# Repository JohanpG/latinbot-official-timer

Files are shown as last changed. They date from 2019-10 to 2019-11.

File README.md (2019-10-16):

# latinbot-official-timer
Project on processing and arduino for the official timer used in the international robotics tournament LATINBOT https://twitter.com/torneolatinbot?lang=en

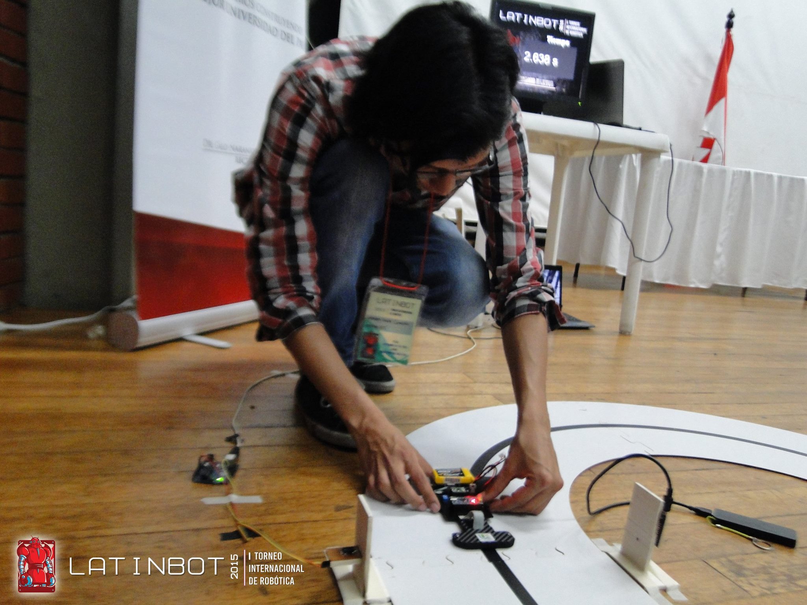
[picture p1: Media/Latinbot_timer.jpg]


# The Sensor

The sensor used was based on a IR Sender and receiver. The PWM on the sender was controller by an Arduino Micro and the Receiver used an Arduino Uno with was conecter via serial to the PC where the processing Application was being executed. Both schematics for the sender and receiver are provided in this repository.

## Sender

[Schematics Here](https://github.com/JohanpG/latinbot-official-timer/blob/master/Schematics/sender.pdf)

## Receiver

[Schematics Here](https://github.com/JohanpG/latinbot-official-timer/blob/master/Schematics/receiver.pdf)
  
# Video

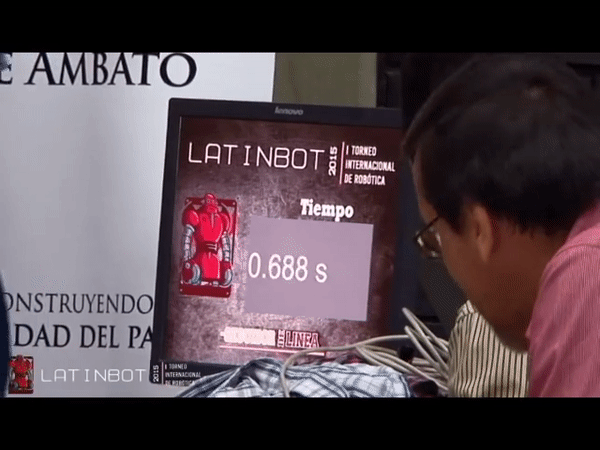
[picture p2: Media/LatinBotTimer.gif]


https://www.youtube.com/watch?v=m9lWtLH9l_A&t=2m27s

# Author

**By: Johan Porras (JohanpG)**

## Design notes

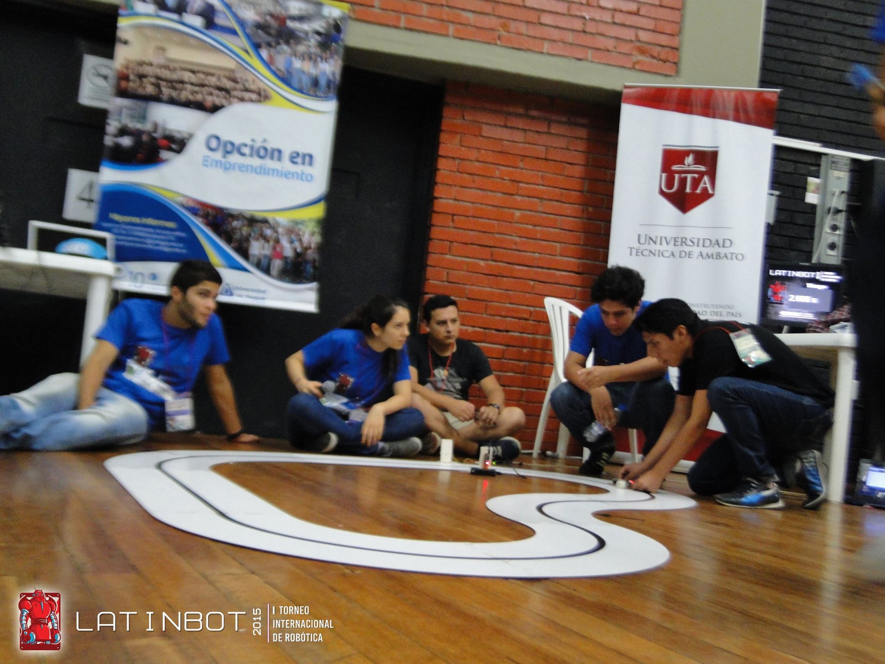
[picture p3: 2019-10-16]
Media/Latinbot_timer2.jpg

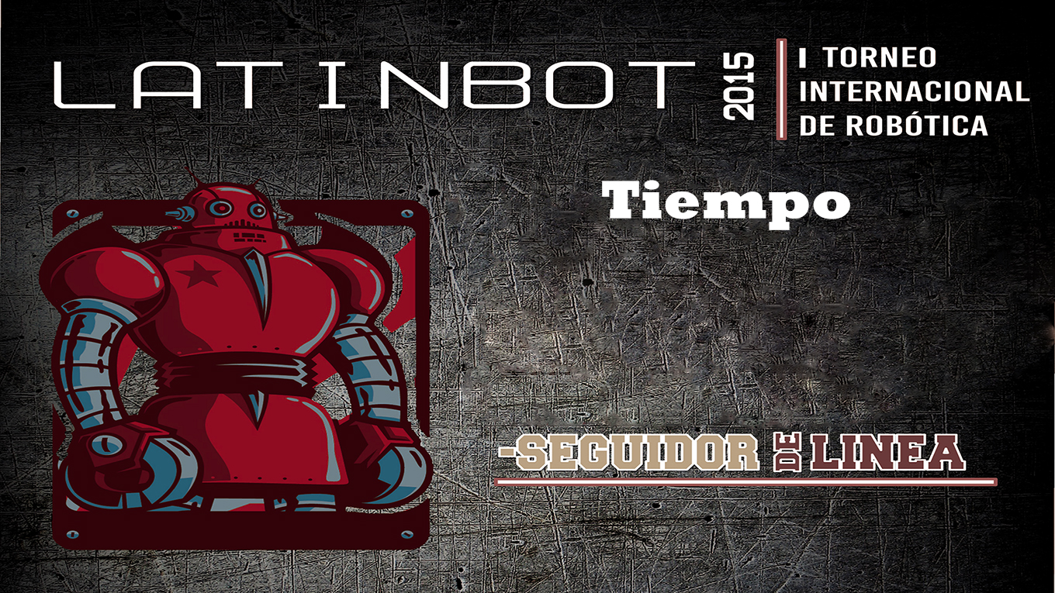
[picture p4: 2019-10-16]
Timer_LatinBot_noArd/images/TimerLatinbot1.jpg

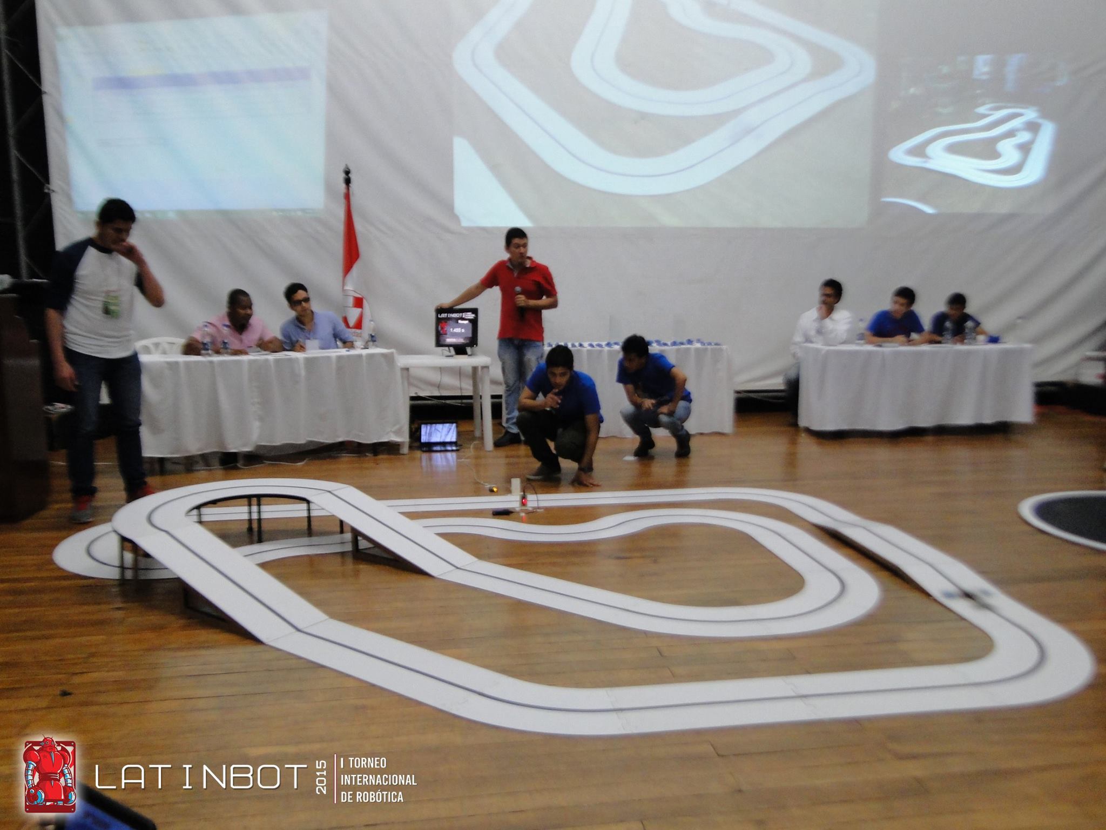
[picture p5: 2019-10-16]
Media/Latinbot_timer3.jpg

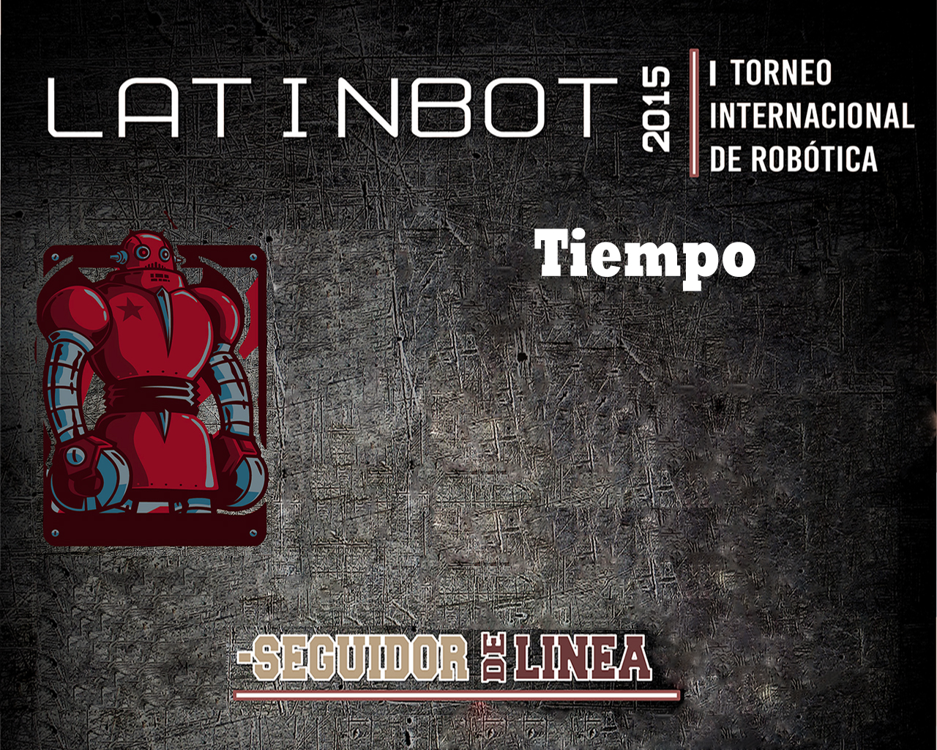
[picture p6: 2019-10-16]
Timer_LatinBot_Live_Sensor/images/TimerLatinbot2.jpg

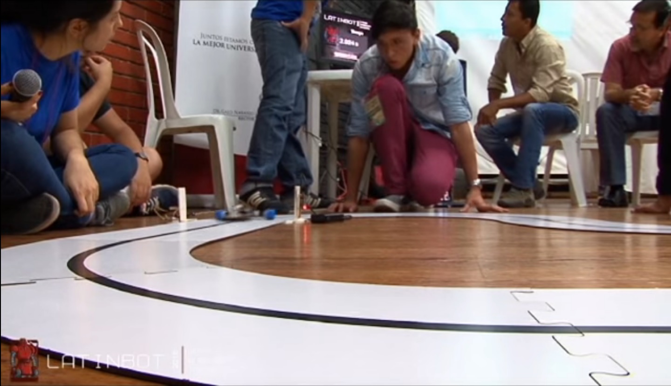
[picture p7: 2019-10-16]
Media/Latinbot_timer4.jpg

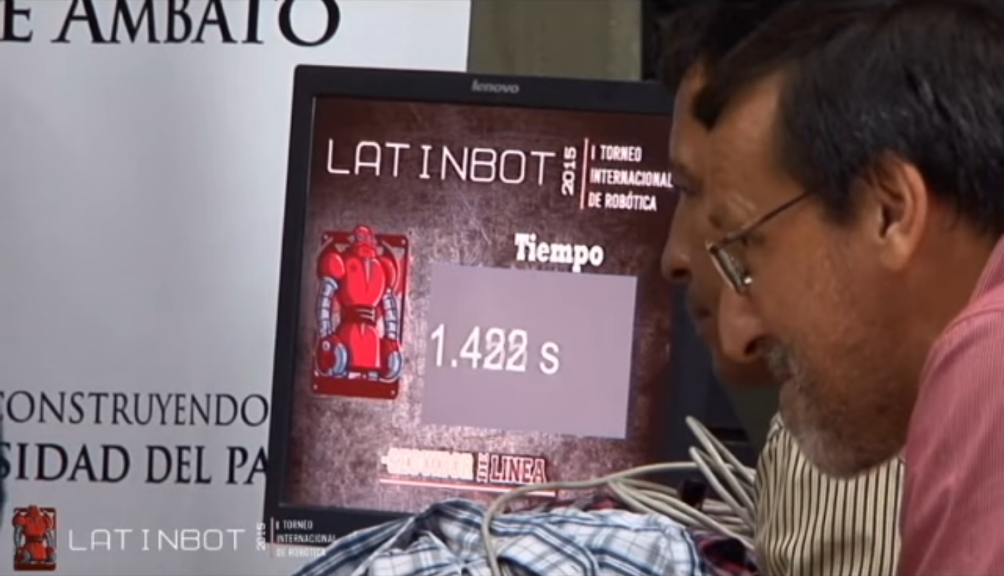
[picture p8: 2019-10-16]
Media/Latinbot_timer5.jpg

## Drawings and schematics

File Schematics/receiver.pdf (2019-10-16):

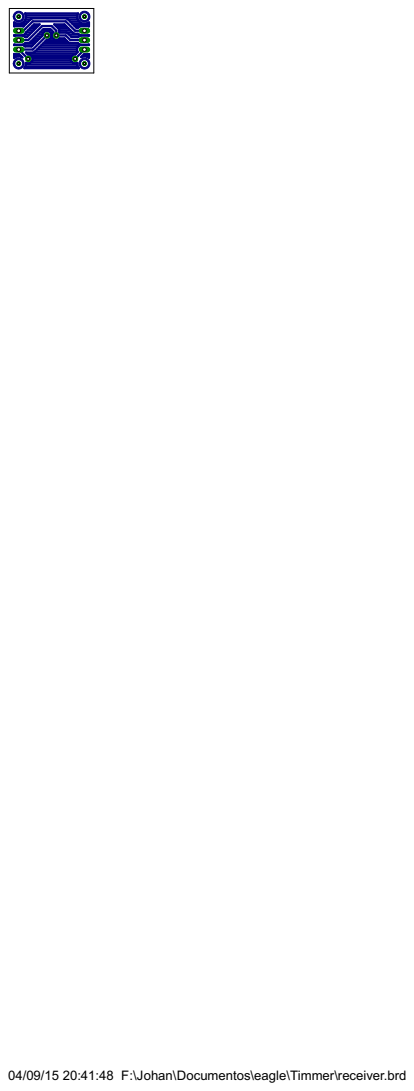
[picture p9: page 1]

04/09/15 20:41:48 F:\Johan\Documentos\eagle\Timmer\receiver.brd

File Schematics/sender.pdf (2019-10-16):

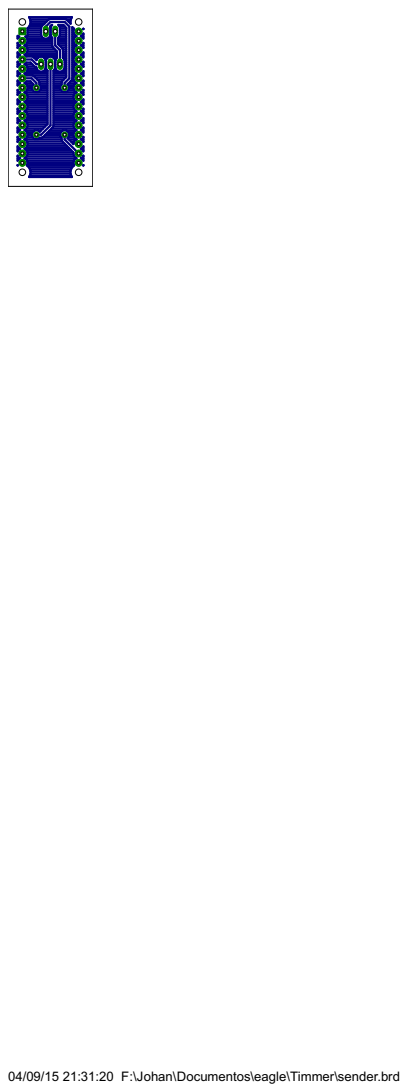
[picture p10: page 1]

04/09/15 21:31:20 F:\Johan\Documentos\eagle\Timmer\sender.brd

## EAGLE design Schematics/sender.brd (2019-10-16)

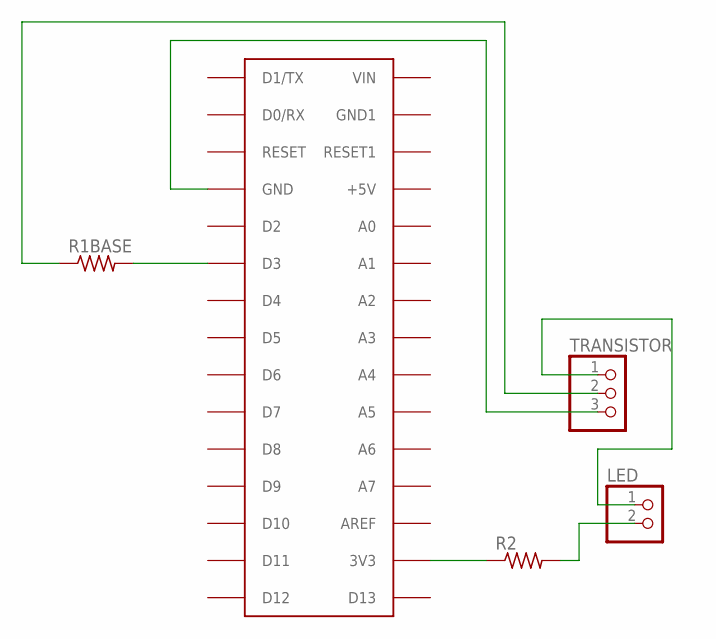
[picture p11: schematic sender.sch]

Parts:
LED: PINHD-1X2; 1X02
R1BASE, R2: R-US_0207/12; 0207/12
TRANSISTOR: PINHD-1X3; 1X03
U$1: ARDUINONANO; PDIP-32

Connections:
unnamed: TRANSISTOR.3, U$1.GND
unnamed: LED.1, TRANSISTOR.1
unnamed: LED.2, R2.2
unnamed: R2.1, U$1.3V3
unnamed: R1BASE.1, TRANSISTOR.2
unnamed: R1BASE.2, U$1.D3

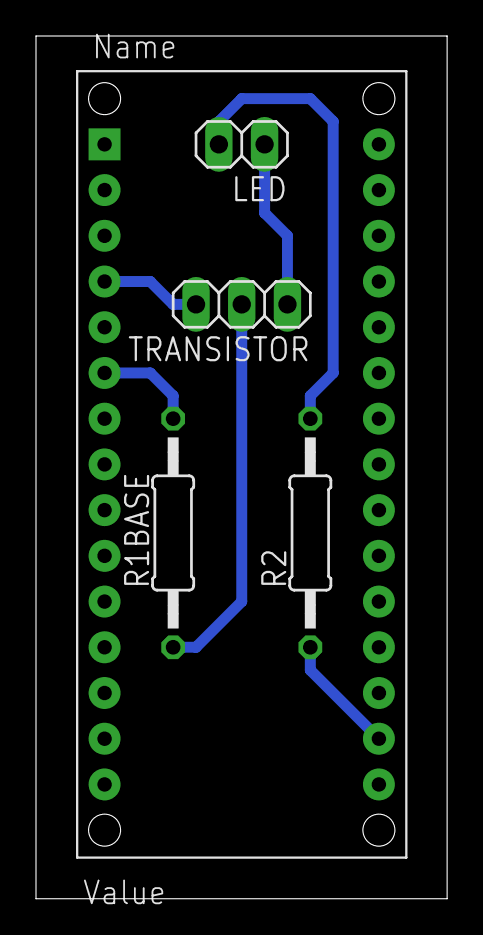
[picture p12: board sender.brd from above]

Board: 2 copper layers, 22.8 x 47.9 mm, 5 parts (0 on the bottom side), 6 nets.

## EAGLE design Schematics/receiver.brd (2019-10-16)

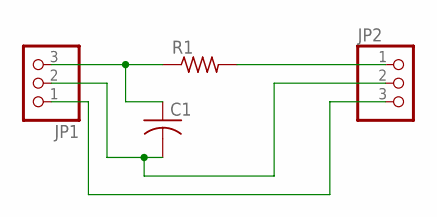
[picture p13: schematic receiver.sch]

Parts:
C1: C-US025-030X050; C025-030X050
JP1, JP2: PINHD-1X3; 1X03
R1: R-US_0207/12; 0207/12

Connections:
unnamed: C1.1, JP1.3, R1.1
unnamed: JP2.1, R1.2
unnamed: C1.2, JP1.2, JP2.2
unnamed: JP1.1, JP2.3

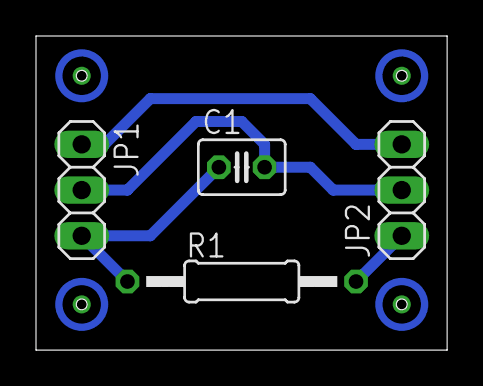
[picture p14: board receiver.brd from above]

Board: 2 copper layers, 22.8 x 17.4 mm, 4 parts (0 on the bottom side), 4 nets.

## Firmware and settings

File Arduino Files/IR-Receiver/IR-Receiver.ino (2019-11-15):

#define PIN_DETECT 2 // This is where the IR detector "out" signal is connected to
#define PIN_STATUS 13 // Used to indicate a break in the barrier, could be a buzzer or something else
 
volatile boolean irbeamup = true; // This value is changed by the Interrupt code 
 boolean flag=false;                                  // and is used both inside and outside the Interrupt code = volatile 
long lastuptime = 0;               // Indicates how many milliseconds since we last had a beam detected
long lapTime = 0; 
long startTime = 0; 
char val; // Data received from the serial port 


void irchanged()
// Interrupt Service Routine for detecting change in the IR reading
// This is connected to Pin 2 on the Arduino
// If there is IR, the value is low, if there is no IR, the value is high
// We want to execute and exit the code as quick as possible, so we only read the value to set the
// boolean irbeamup flag
 
{
   if (digitalRead(PIN_DETECT) == LOW) irbeamup = true;
   else irbeamup = false;
}
 
void setup()
{
    Serial.begin(9600); // Start serial communication at 9600 bps
    pinMode(PIN_DETECT, INPUT);             // This is where we read the IR detector
    pinMode(PIN_STATUS, OUTPUT);            // To show some status
    attachInterrupt(digitalPinToInterrupt(PIN_DETECT), irchanged, CHANGE);  // Here the magic is happening: On a CHANGE on Port 0 (Pin 2), 
                                            // the irchanged function will interrupt whatever is going on
}
 
void loop() {
  if (Serial.available()) 
   { // If data is available to read,
     val = Serial.read(); // read it and store it in val
   }
   if (val == '1') 
   { // If 1 was received
   
     startTime=millis();
     flag=true;
     val == '0';
    
   } else {
     startTime=0;
     val == '0';
     
   }

   if ((irbeamup == true) && (flag==true)) {                     // We have a beam 
        lastuptime = millis();                 // So set the current time to lastuptime
        digitalWrite(PIN_STATUS, HIGH);        // Light the LED, we have a beam
   }
   else {                                      // A break in the beam was detected
                                               // However, if less than 100 mS since last IR was detected,
                                               // I do not yet indicate a break
        if ((millis() - lastuptime > 5)&& (flag==true)) {
                  digitalWrite(PIN_STATUS, LOW);
                  lapTime=millis()-startTime;
                  Serial.println(lapTime);
                  Serial.flush();
                  flag=false;
                  // Other actions for the break. We know we last had a beam at lastuptime.
        }
        else{
          }
   }
}

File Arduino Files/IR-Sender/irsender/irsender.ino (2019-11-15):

const byte LED = 3;  // Timer 2 "B" output: OC2B

#define PIN_IR 3
#define PIN_DETECT 2
#define PIN_STATUS 5

const long frequency = 38000L;  // Hz

void setup() 
{
  pinMode (LED, OUTPUT);

  TCCR2A = bit (WGM20) | bit (WGM21) | bit (COM2B1); // fast PWM, clear OC2B on compare
  TCCR2B = bit (WGM22) | bit (CS21);         // fast PWM, prescaler of 8
  OCR2A =  ((F_CPU / 8) / frequency) - 1;    // zero relative  
  OCR2B = ((OCR2A + 1) / 4) - 1;             // 50% duty cycle
//  pinMode(PIN_DETECT, INPUT);
//  pinMode(PIN_STATUS, OUTPUT);
//
//  Serial.begin(9600);
}  // end of setup

void loop()
{

//  digitalWrite(PIN_STATUS, !digitalRead(PIN_DETECT));
//  Serial.println(!digitalRead(PIN_DETECT));
  delay(100);
}

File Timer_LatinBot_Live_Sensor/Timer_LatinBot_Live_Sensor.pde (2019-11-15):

import controlP5.*;
import java.nio.ByteBuffer;
import processing.serial.*;
PImage bg;
int y;
float Input, Setpoint, Output;
String val="0.0";
float valor=0.0;

double nowTime=0;
boolean flag= false;
Serial myPort;

ControlP5 controlP5;
controlP5.Textfield myfield1,myfield;
controlP5.Button b;
void setup() {
  frame.removeNotify();
  frame.setUndecorated(true);
  frame.addNotify(); 
  frameRate(30);
  size(1280, 1024);
  println(Serial.list());                                           // * Initialize Serial
  myPort = new Serial(this, Serial.list()[0], 9600);                //   Communication with
  myPort.bufferUntil('\n'); 
  // The background image must be the same size as the parameters
  // into the size() method. In this program, the size of the image
  // is 640 x 360 pixels.
  bg = loadImage("/images/TimerLatinbot2.jpg");
  controlP5 = new ControlP5(this); 

  
   ControlFont cf1 = new ControlFont(createFont("Arial",140));
   ControlFont cf2 = new ControlFont(createFont("Arial",20));
   createField("",450,400,700,400,color(255,0,0),cf1);
  // SPField= controlP5.addTextfield("",750,330,400,200);
}
Button createButton(String theName, int theValue, int theX, int theY, color theColor, ControlFont theFont) {
  Button b = controlP5.addButton(theName,theValue,theX,theY,143,80);
  b.setColorActive(theColor); // color for mouse-over
  b.setColorBackground(color(90)); // default color
  b.captionLabel().setControlFont(theFont);
  return b;
}

Textfield createField(String theName, int theX, int theY,int theW,int theH, color theColor, ControlFont theFont) {
   myfield = controlP5.addTextfield(theName,theX,theY,theW,theH);
  // myfield.setColorActive(theColor); // color for mouse-over
  myfield.setColorBackground(color(90)); // default color
  myfield.captionLabel().setControlFont(theFont);
  myfield.setFont(theFont);
  return myfield;
}



void draw() {
  background(bg);
 
  myfield.setText(valor/1000 +" s");

  
 
}

void keyPressed(){
     if (key == ESC) { //The ASCII code for esc is 27, so therefore: 27
     //insert your function here
     key=0 ;
     // Clear the buffer, or available() will still be > 0
      myPort.clear();
      // Close the port
      myPort.stop();
      println(" I'm done!");
      exit();
   
}
} 


void controlEvent(ControlEvent theEvent) {
if(theEvent.isController()) { 
    
    print("control event from : "+theEvent.controller().name());
    println(", value : "+theEvent.controller().value());
    
  
  }
}

void serialEvent( Serial myPort) {
//put the incoming data into a String - 
//the '\n' is our end delimiter indicating the end of a complete packet
val = myPort.readStringUntil('\n');
//make sure our data isn't empty before continuing
if (val != null) {
  //trim whitespace and formatting characters (like carriage return)
//  val = trim(val);
  println(val);
  valor=Float.parseFloat(val);
  
}
}
